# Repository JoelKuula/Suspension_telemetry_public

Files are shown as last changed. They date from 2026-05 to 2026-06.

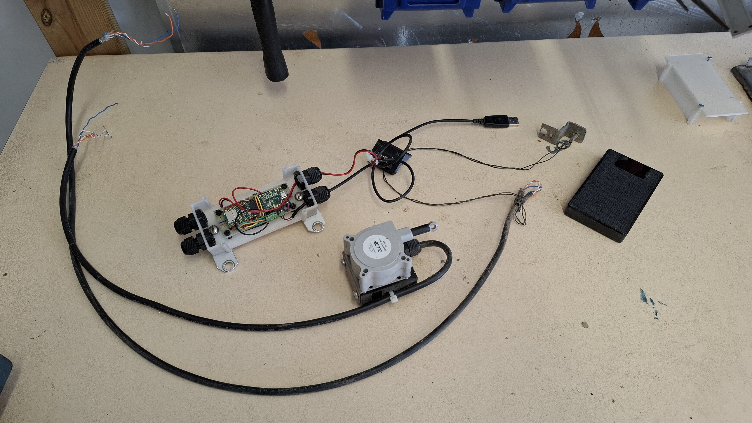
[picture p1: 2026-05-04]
pictures/bom-1.jpg

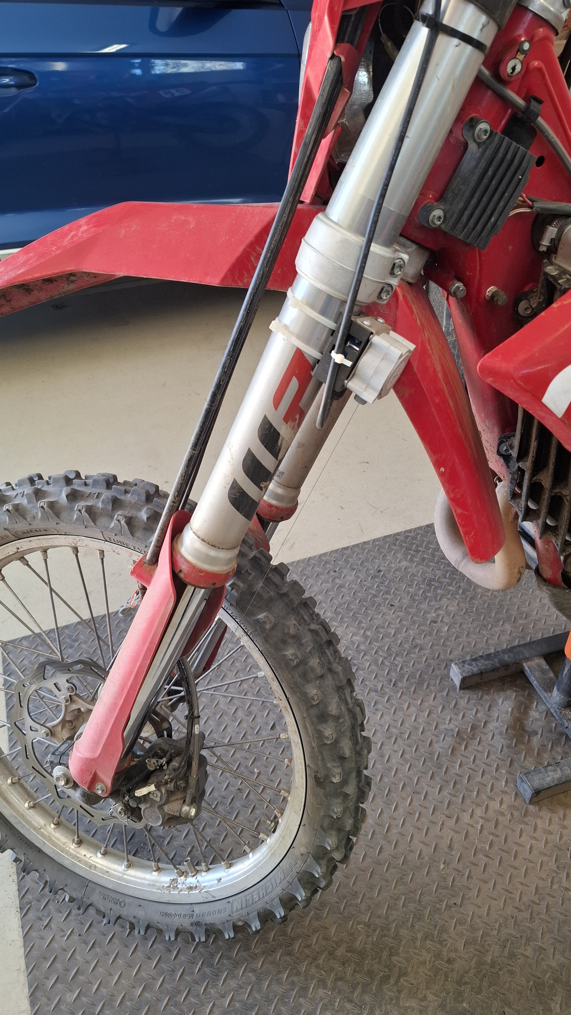
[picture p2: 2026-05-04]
pictures/installation-on-fork.jpg

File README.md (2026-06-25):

# Suspension Telemetry

DIY suspension telemetry logger and post-processing tools for enduro and motocross bikes.

The current project state is a prototype. The active logger slice uses a Teensy 4.1 to record front fork travel, rear shock stroke, front wheel pulse timing, status records, and RTC-backed session start timestamps.

This repo is intended to be useful to riders and builders who want to inspect, adapt, or improve the system. It is not a certified product or a complete suspension tuning solution.

## Prototype Status
- Active firmware scope: analog travel logging, front wheel pulse logging, status diagnostics, RTC-backed session metadata, and microSD binary session files.
- Active hardware baseline: Teensy 4.1, string potentiometer travel sensors (front only for now), front wheel reed switch, handlebar logging switch, microSD storage, RTC battery, and USB power-bank supply.
- Active analysis scope: binary inspection/export, desktop post-processing, occupancy/histogram views, speed checks, balance views (tbd), braking analysis, breakdown tables (tbd), and comparison workflows.

Read [`DISCLAIMER.md`](DISCLAIMER.md) before using this on a bike.

For the first public snapshot, see [`RELEASE_NOTES.md`](RELEASE_NOTES.md).

## Repository Layout
- [`HARDWARE.md`](HARDWARE.md): current hardware stack, mounting assumptions, and pinout.
- [`platformio.ini`](platformio.ini): PlatformIO project configuration for Teensy 4.1 firmware.
- [`src/main.cpp`](src/main.cpp): current integrated logger firmware.
- [`src/uploadcheck_blink.cpp`](src/uploadcheck_blink.cpp): minimal upload-check firmware using the external status LED on pin `14`.
- [`scripts/inspect_log.py`](scripts/inspect_log.py): parser and structural sanity checker for `.BIN` session files.
- [`scripts/export_log.py`](scripts/export_log.py): exporter from `.BIN` session files to CSV outputs.
- [`scripts/log_parser.py`](scripts/log_parser.py): shared binary parser used by the inspection and export tools.
- [`scripts/plot_occupancy_surface.py`](scripts/plot_occupancy_surface.py): CLI occupancy heatmap plotter.
- [`scripts/postprocess_gui.py`](scripts/postprocess_gui.py): desktop post-processing workbench launcher.
- [`scripts/postprocess_gui_app/`](scripts/postprocess_gui_app): shared backend services and PySide6 GUI implementation.
- [`scripts/postprocess_quicklook.py`](scripts/postprocess_quicklook.py): experimental Qt-free summary generator for `.BIN` files or existing exports.
- [`notebooks/trackside_quicklook.ipynb`](notebooks/trackside_quicklook.ipynb): experimental Colab wrapper for the quicklook path.
- [`data/`](data): sample raw `.BIN` sessions for parser, exporter, GUI, and analysis experiments.
- [`installation-pics/`](installation-pics): installation reference photos.
- [`3d-printed-parts-stl/`](3d-printed-parts-stl): STL files for prototype printed parts.
- [`tests/`](tests): backend and GUI regression tests for the analysis tooling.
- [`requirements.txt`](requirements.txt): Python dependencies for the post-processing tools.

Generated exports are intentionally not tracked. Running the exporter or GUI creates `exports/<session>/` locally.

## Quick Start
1. Read [`HARDWARE.md`](HARDWARE.md) before changing firmware, wiring, mounting, or sensor assumptions.
2. Install Python dependencies for post-processing:
   ```powershell
   python -m pip install -r requirements.txt
   ```
3. Inspect a sample log:
   ```powershell
   python scripts/inspect_log.py data/LOG00036.BIN
   ```
4. Export a sample log:
   ```powershell
   python scripts/export_log.py data/LOG00036.BIN --output-dir exports/LOG00036
   ```
5. Launch the desktop workbench on Windows:
   ```powershell
   .\postprocess_gui.cmd
   ```

The workbench can open a raw `.BIN` file and refresh `exports/<session>/`, or open an existing local export folder directly. GUI-derived caches and plots live under `exports/<session>/analysis/` and are generated locally.

## Firmware
The current integrated firmware target is the analog-plus-wheel ride logger in [`src/main.cpp`](src/main.cpp). It is designed around:
- deterministic analog sampling,
- wheel pulses as timestamped events,
- status records for boot/session/fault evidence,
- RTC-backed session start metadata,
- SD storage as a background path rather than an acquisition timing dependency.

Build with PlatformIO:
```powershell
platformio run -e teensy41
```

Use the upload-check firmware only when USB programming behavior needs to be isolated from the logger:
```powershell
platformio run -e teensy41_uploadcheck
```

## Desktop Workbench
Main views:
- `Session`: export summary, record counts, and status/fault rows.
- `Histograms`: front and rear travel plus velocity occupancy distributions.
- `Occupancy`: front and rear velocity-travel heatmaps.
- `Balance`: front/rear normalized travel comparison (tbd).
- `Braking`: front braking behavior.
- `Breakdown`: riding-state, event, finding, and data-quality tables (tbd).
- `Speed`: front wheel pulse-derived speed and pulse period.
- `Metrics`: per-channel stroke, velocity, and ADC checks.
- `Compare`: multi-session comparison workflow.

Per-session calibration is stored locally in `exports/<session>/analysis/session_config.json`.

## Experimental Quicklook
The quicklook path exists, but it is not the primary supported workflow yet. It can generate a small text/JSON summary and two figures without the PySide6 desktop GUI:
```powershell
python scripts/postprocess_quicklook.py --input data/LOG00036.BIN
```

Default outputs are written under `exports/<session>/analysis/quicklook/`.

## Sample Data
The repo keeps selected raw `.BIN` files under [`data/`](data), including the newer `LOG00041.BIN` through `LOG00053.BIN` sessions, so users can try the parser, exporter, quicklook script, GUI, and braking-analysis workflow without first building hardware.

Generated CSV exports, derived Parquet caches, plots, and per-session local calibration files are ignored because they can be regenerated from the raw `.BIN` files.

## Safety And Secrets
- Do not commit secrets, credentials, tokens, private keys, or private ride metadata.
- Treat bike-mounted hardware changes as safety-relevant.
- Verify wiring, power, waterproofing, and mechanical clearance before riding.
- Do not rely on the analysis output as professional suspension advice.

## License
This project is released under the [`MIT License`](LICENSE). MIT is permissive: others may use, copy, modify, merge, publish, distribute, sublicense, and sell copies, but the copyright and permission notice must be included with copies or substantial portions of the project.

## Contributing
Focused improvements are welcome. Please keep hardware assumptions explicit, preserve raw timing/data-model traceability, and update README/HARDWARE when architecture, hardware, wiring, or scope changes materially.

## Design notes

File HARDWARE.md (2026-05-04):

# HARDWARE

Current hardware baseline for the suspension telemetry logger.

## In Use Now
- MCU and logger: Teensy 4.1
- RTC backup: Teensy 4.1 RTC with CR2032 backup battery
- IMU hardware retained for later: SparkFun 6DoF IMU Breakout, `ISM330DHCX` (`SEN-19764`)
- Travel sensor currently installed: TE Connectivity `SP1-25` string potentiometer for fork testing
- Planned second travel sensor: likely TE Connectivity `SP1-12` for shock testing after fork validation
- Speed sensor: front wheel reed switch plus magnet
- Storage: Teensy 4.1 microSD
- User control: handlebar-mounted latching rocker switch for logging start and stop
- Power: USB power bank into the Teensy USB connector
- Packaging target: rigid under-seat enclosure near the bike center mass

## Current State
- The logger has already powered up and run successfully in bench-style living-room testing.
- The active firmware slice logs analog travel, front wheel speed, status events, and RTC-backed session start metadata.
- The IMU hardware is the `ISM330DHCX`, but active IMU logging is deferred until the enclosure and mounting arrangement are rigid enough for meaningful data.
- When IMU logging returns, it will use primary 4-wire SPI, not Qwiic or I2C.
- The intended long-term IMU mounting location remains under the seat on a rigidly mounted logger assembly.
- Logged bike-axis convention is `+X forward`, `+Y left`, `+Z up`.
- Rear suspension measurement remains raw shock stroke only; any wheel-travel conversion is an offline step.
- Wheel speed comes from the front wheel only.
- The string pot excitation baseline is the Teensy `3.3V` rail.
- Teensy 4.1 `LED_BUILTIN` shares pin `13`, so firmware must not use the built-in LED while pin `13` is the IMU SPI clock.
- The RTC remains in use because wall-clock session start times are useful for later BIN indexing and database work.
- Remaining hardware details to finalize later: analog filtering and protection, power-bank auto-shutdown mitigation, IMU remounting, and environmental sealing.

## IMU SPI Wiring
Reserved for the future IMU-return slice; not used by the current analog-plus-wheel firmware.

SparkFun labels the SPI pins from the sensor-board side:
- `SCL/SPC` -> Teensy pin `13` (`SCK`)
- `SDA/SDI` -> Teensy pin `11` (`PICO/MOSI`)
- `SDO/SA0` -> Teensy pin `12` (`POCI/MISO`)
- `CS` -> Teensy pin `10`
- `INT1` -> Teensy pin `2`
- `INT2` -> Teensy pin `3` if needed later

Do not confuse these with the auxiliary interface pins such as `SDX`, `SCX`, `SDO_AUX`, `POCI_AUX`, or `OCS_AUX`.

## Pinout

| Function | Device wire / signal | Teensy 4.1 pin | Notes |
| --- | --- | --- | --- |
| Fork travel sensor | `SP1-25 +in` | `3.3V` | Excitation supply |
| Fork travel sensor | `SP1-25 common` | `GND` | Sensor ground |
| Fork travel sensor | `SP1-25 +out / wiper` | `20 (A6)` | Analog input |
| Shock travel sensor, planned | `SP1-12 +in` | `3.3V` | Planned second analog channel |
| Shock travel sensor, planned | `SP1-12 common` | `GND` | Planned second analog ground |
| Shock travel sensor, planned | `SP1-12 +out / wiper` | `19 (A5)` | Planned second analog input |
| IMU power | `VCC` | `3.3V` | SparkFun board is `3.3V` logic and supply |
| IMU power | `GND` | `GND` | Common ground |
| IMU SPI | `SCL / SPC` | `13` | SPI clock |
| IMU SPI | `SDA / SDI` | `11` | Teensy `PICO/MOSI` |
| IMU SPI | `SDO / SA0` | `12` | Teensy `POCI/MISO` |
| IMU SPI | `CS` | `10` | Chip select |
| IMU interrupt | `INT1` | `2` | Reserved for future IMU-return slice |
| IMU interrupt, optional | `INT2` | `3` | Reserve if needed later |
| Wheel speed | Reed switch wire 1 | `18` | Configure as `INPUT_PULLUP` |
| Wheel speed | Reed switch wire 2 | `GND` | Switch closes to ground |
| Handlebar logging switch | Switch wire 1 | `17` | Configure as `INPUT_PULLUP`; flipped on pulls the pin low |
| Handlebar logging switch | Switch wire 2 | `GND` | Latching switch returns high when flipped off |
| USB power | Teensy USB connector | USB power bank | Main supply path |

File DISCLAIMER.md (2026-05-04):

# Disclaimer

This repository documents and implements a DIY prototype telemetry logger for motorcycle suspension development. It is not a certified safety device, commercial product, professional suspension tuning system, or substitute for mechanical inspection and judgment.

Use this project at your own risk. Verify all wiring, mounting, waterproofing, strain relief, power supply behavior, sensor clearances, and enclosure retention before riding. A loose sensor, cable, printed part, enclosure, or battery can interfere with motorcycle controls or moving parts.

The firmware, hardware notes, 3D models, photos, data files, scripts, analysis outputs, and documentation are provided without warranty. The author is not responsible for injury, damage, data loss, incorrect measurements, incorrect tuning decisions, regulatory issues, or any other consequence from using or adapting this project.

Analysis results are experimental. They may be wrong because of calibration errors, sensor noise, mounting flex, missed pulses, file corruption, software bugs, or incorrect assumptions about the motorcycle. Validate any conclusion independently before changing suspension setup or riding behavior.

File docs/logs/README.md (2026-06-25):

# Task Log Archives

Use this folder for archived task history when the active `TASK_LOG.md` becomes hard to scan.

## Naming Convention
Use one of these patterns:
- `TASK_LOG_YYYY_Q1.md`
- `TASK_LOG_YYYY_Q2.md`
- `TASK_LOG_YYYY_Q3.md`
- `TASK_LOG_YYYY_Q4.md`
- `TASK_LOG_<phase>.md`

Quarter-based naming is the default. Phase-based naming is fine when the project has clear stages and quarter splits would be less useful.

## Archive Trigger Rule
Archive older entries when the active `TASK_LOG.md` becomes hard to scan during normal work.

Signals that it is time to archive:
- important recent entries are getting buried,
- the file is slow to review at task start,
- the log contains multiple completed phases that no longer need to stay in the active file.

## Archive Rules
- Keep `TASK_LOG.md` as the active working log.
- Move only older completed entries into archive files.
- Preserve chronological order inside each archive file.
- Leave recent or currently relevant entries in the active log.
- Add a short note in `TASK_LOG.md` if a large archive move would otherwise confuse future readers.

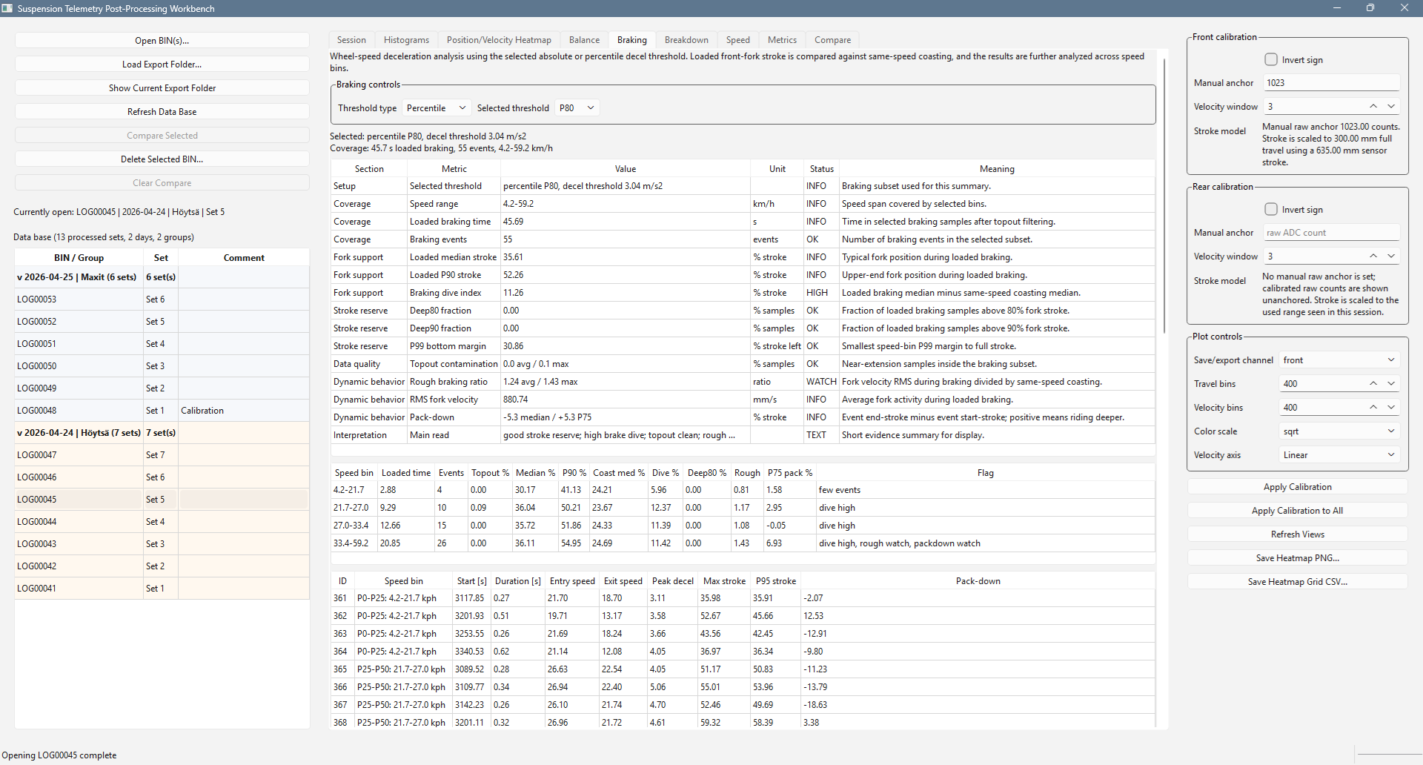
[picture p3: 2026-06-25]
pictures/workbench-example-braking.png

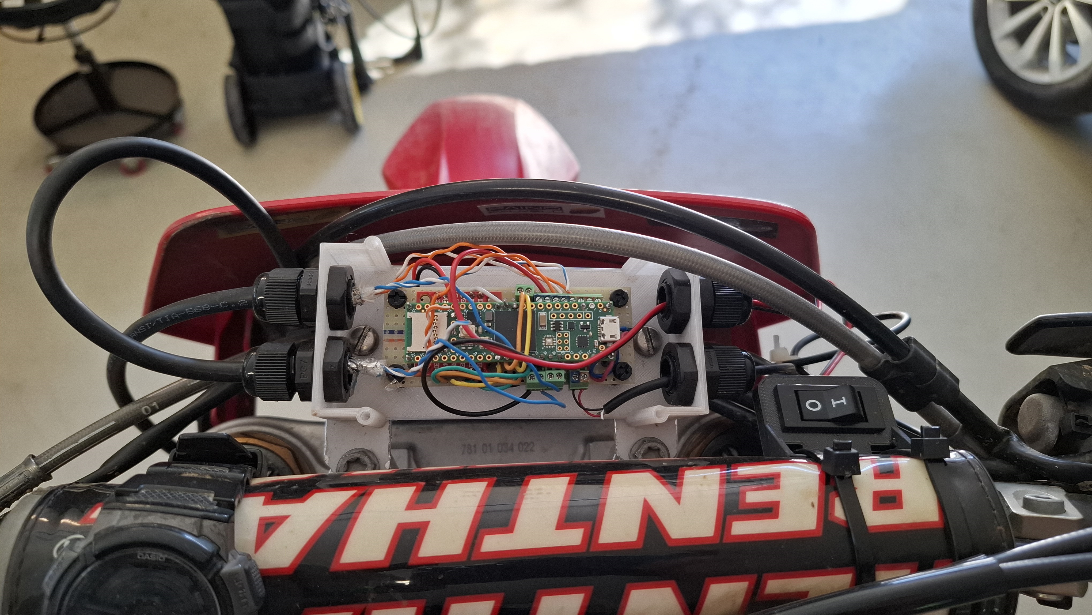
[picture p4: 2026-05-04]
pictures/pcb-mounting.jpg

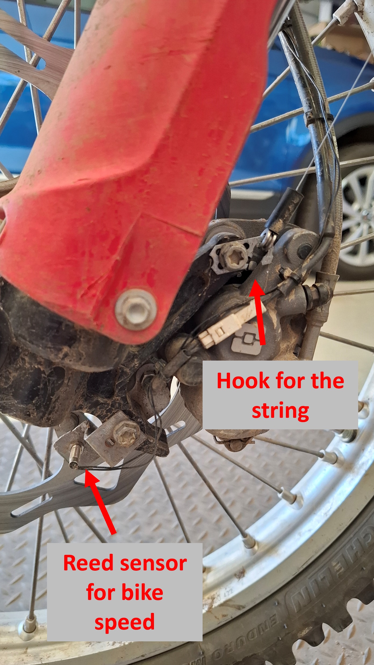
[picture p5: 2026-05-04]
pictures/string-pot-attachment-and-speed-sensor.png

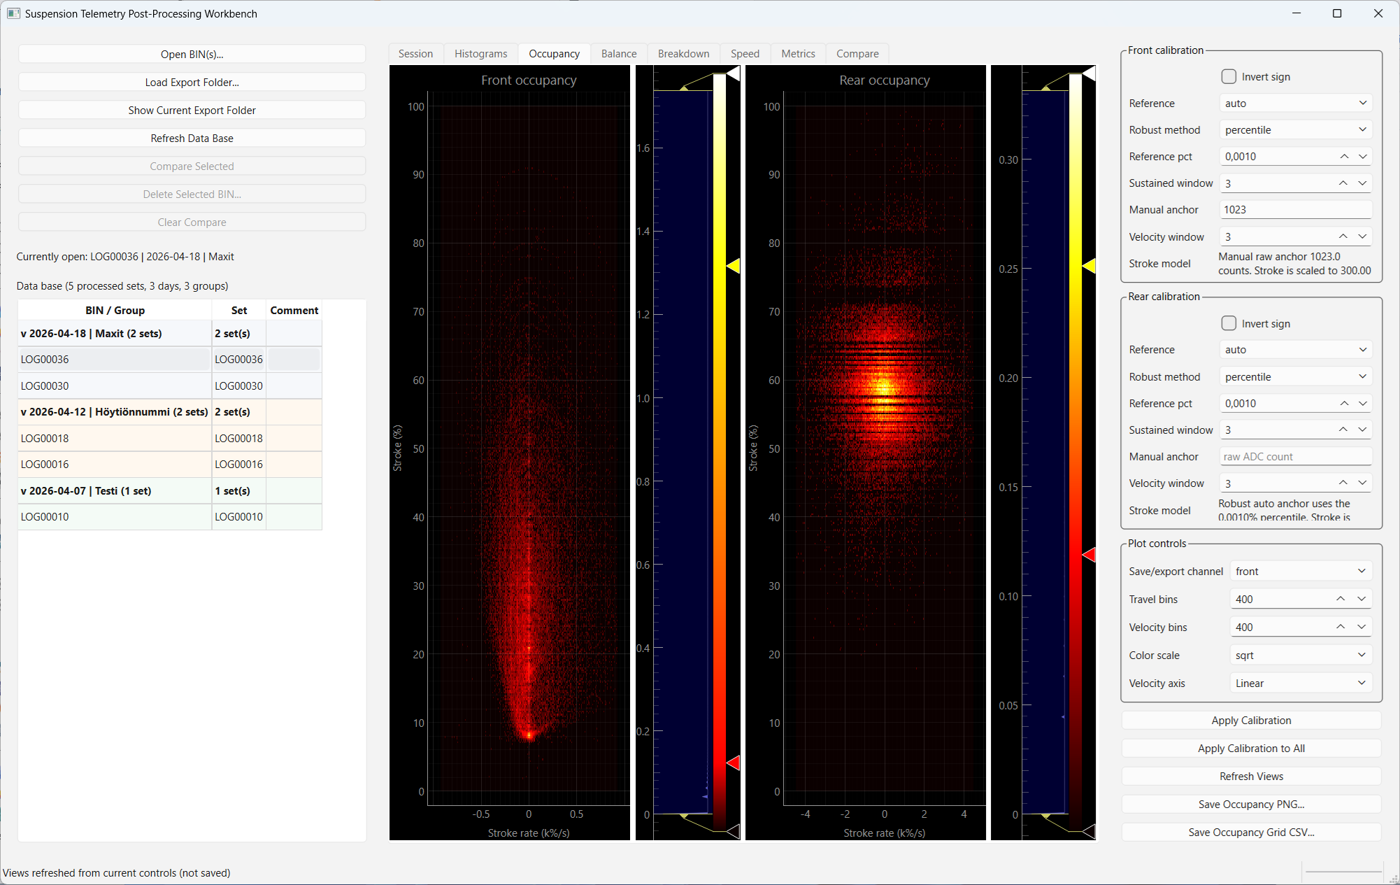
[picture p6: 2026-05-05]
pictures/workbench-example-2.png

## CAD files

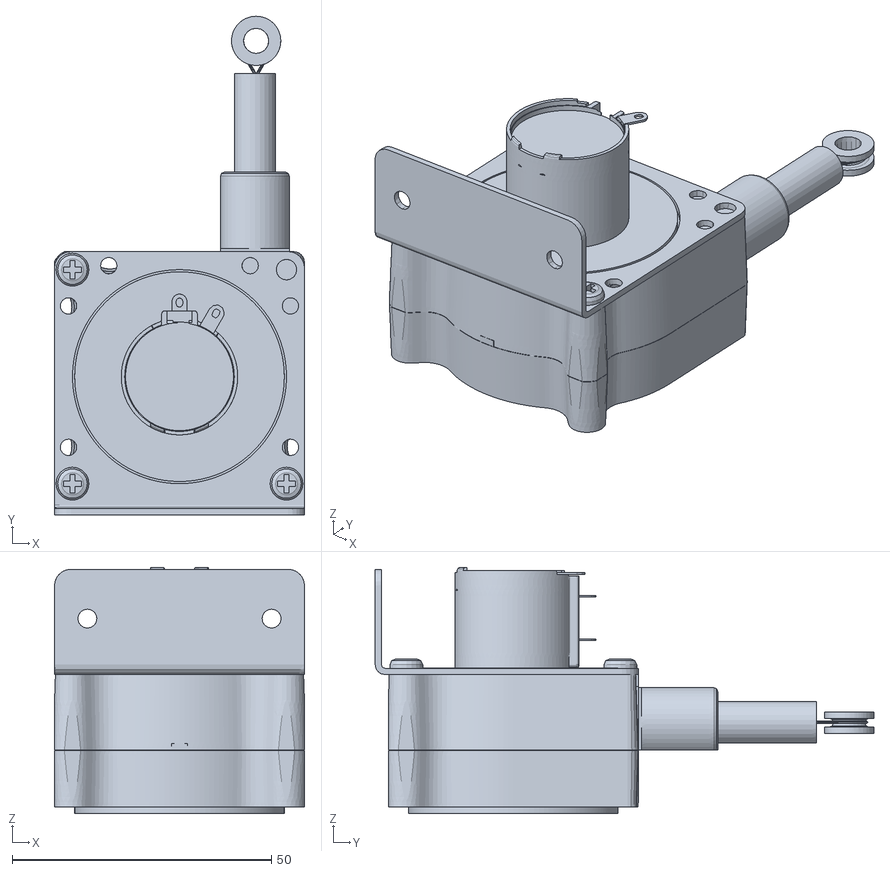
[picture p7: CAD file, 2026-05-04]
3d-printed-parts-stl/sp1-12.stl
48.3 x 96.3 x 47.6

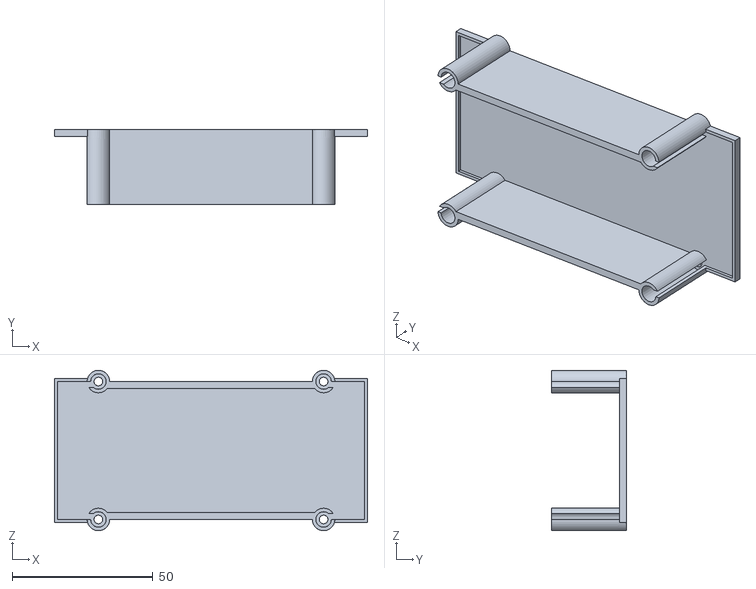
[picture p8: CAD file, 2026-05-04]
3d-printed-parts-stl/lid.stl
111.2 x 26.5 x 57.0

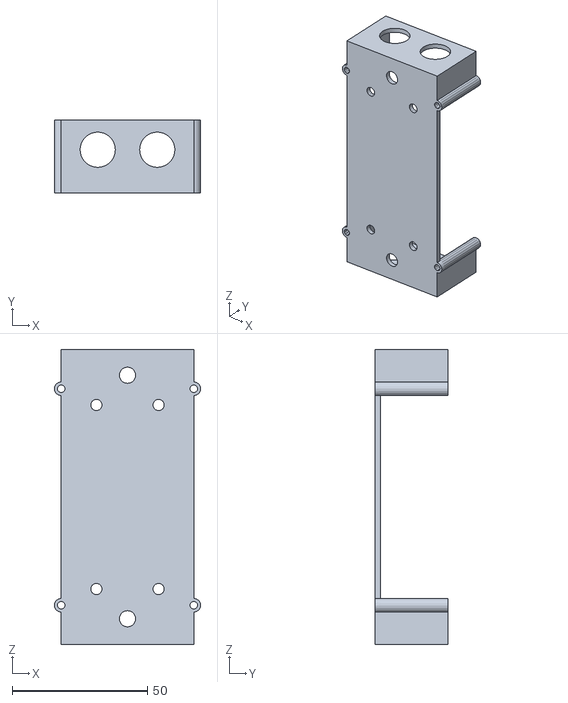
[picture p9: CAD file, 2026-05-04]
3d-printed-parts-stl/box.stl
54.0 x 27.0 x 109.0

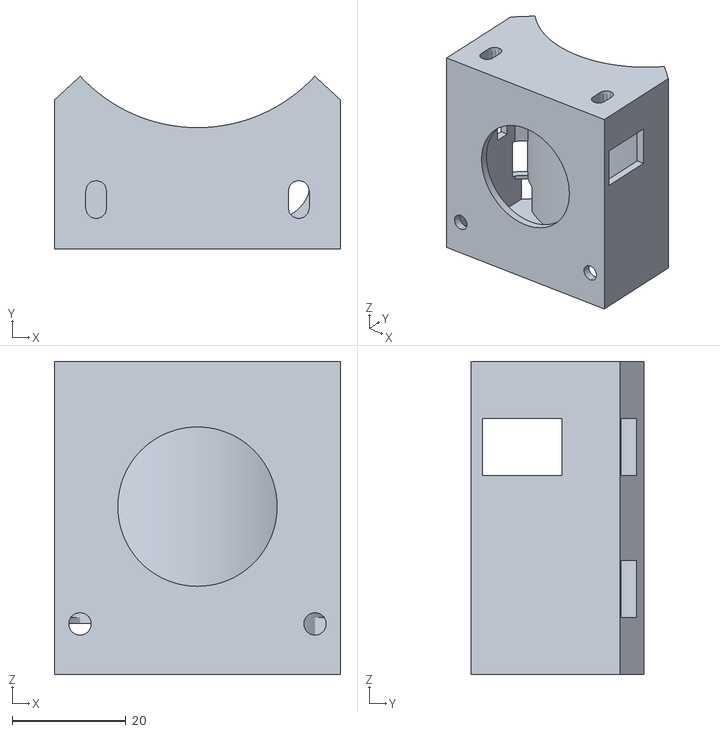
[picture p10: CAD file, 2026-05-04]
3d-printed-parts-stl/sp1_bracket.stl
50.3 x 30.3 x 55.0

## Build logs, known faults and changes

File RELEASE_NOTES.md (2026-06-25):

# v0.1-prototype

First public prototype snapshot of the DIY suspension telemetry project.

## Included
- Teensy 4.1 analog-plus-wheel logger firmware.
- Hardware wiring reference.
- Sample `.BIN` log files for parser, exporter, quicklook, and GUI experiments.
- Python parser/export tools.
- Desktop post-processing GUI.
- Experimental quicklook script and Colab notebook.
- Installation reference photos.
- Prototype STL files for printed parts.

## Post-processing GUI update
- Added the Python Braking view.
- Added newer raw `.BIN` sample sessions (`LOG00041.BIN` through `LOG00053.BIN`) so people can try the current GUI and analysis paths with real data.

## Known Limitations
- Prototype only; not a certified safety device or professional suspension tuning system.
- Active IMU logging is deferred until the logger can be mounted rigidly enough for useful inertial data.
- Analysis outputs are experimental and may be affected by calibration, sensor noise, mounting flex, missed pulses, or software bugs.
- Generated `exports/` are not tracked and should be regenerated from `.BIN` files.
- Rear channel represents shock stroke, not rear wheel travel.

## Safety
Read `DISCLAIMER.md` before using this project on a motorcycle.

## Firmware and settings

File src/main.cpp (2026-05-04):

#include <Arduino.h>
#include <IntervalTimer.h>
#include <SD.h>
#include <TimeLib.h>

#include <cstdio>
#include <cstring>

namespace {

constexpr uint8_t kButtonPin = 17;
constexpr uint8_t kLedPin = 14;
constexpr uint8_t kReedPin = 18;
constexpr uint8_t kFrontPotPin = A6;
constexpr uint8_t kRearPotPin = A5;
constexpr uint8_t kImuCsPin = 10;
constexpr uint8_t kImuInt1Pin = 2;

constexpr uint32_t kDebounceMs = 20;
constexpr uint32_t kArmBlinkMs = 120;

constexpr uint32_t kAnalogSampleRateHz = 500;
constexpr uint32_t kAnalogTimerPeriodUs = 1000000UL / kAnalogSampleRateHz;
constexpr uint8_t kAnalogResolutionBits = 12;
constexpr uint8_t kAnalogAveraging = 8;
// At 500 Hz each pending slot represents 2 ms of service latency. Eight slots
// were not enough to ride through occasional SD flush stalls seen in ride logs,
// so keep a larger timestamp cushion without changing the sample schedule.
constexpr uint16_t kAnalogMaxPendingTicks = 32;
constexpr uint8_t kAnalogTimestampCapacity = kAnalogMaxPendingTicks;

constexpr uint32_t kReedDebounceUs = 3000;
constexpr float kWheelCircumferenceM = 2.213f;

constexpr size_t kWriterBufferBytes = 65536;
constexpr size_t kWriterChunkBytes = 1024;
constexpr uint32_t kWriterFlushIntervalMs = 250;
constexpr uint32_t kFlushTimeoutMs = 5000;

constexpr uint32_t kMinValidRtcEpoch = 1704067200UL;
constexpr uint16_t kFormatVersion = 1;
constexpr uint32_t kFirmwareVersion = 0x00010000UL;

#ifdef LOGGER_VALIDATION_AUTORUN
constexpr uint32_t kValidationStartDelayMs = 12000;
constexpr uint32_t kValidationRunDurationMs = LOGGER_VALIDATION_DURATION_MS;
#endif

constexpr uint8_t kSensorMaskFrontAnalog = 0x01;
constexpr uint8_t kSensorMaskRearAnalog = 0x02;
constexpr uint8_t kSensorMaskWheel = 0x04;
constexpr uint8_t kSensorMaskRtc = 0x10;

enum class LoggerState : uint8_t {
  IDLE,
  LOGGING,
};

enum class StatCode : uint16_t {
  BOOT = 1,
  RTC_VALID = 2,
  RTC_INVALID = 3,
  SD_READY = 4,
  SD_ERROR = 5,
  IMU_READY = 6,
  IMU_ERROR = 7,
  SESSION_START = 8,
  SESSION_STOP = 9,
  CLEAN_CLOSE = 10,
  QUEUE_OVERFLOW = 11,
  ANALOG_OVERRUN = 12,
  REED_OVERFLOW = 13,
  IMU_FIFO_OVERFLOW = 14,
  WRITER_ERROR = 15,
  IMU_READ_ERROR = 16,
};

enum class SessionStopReason : int32_t {
  UNKNOWN = 0,
  SWITCH_OFF = 1,
  VALIDATION_AUTORUN = 2,
};

struct RingBuffer {
  uint8_t data[kWriterBufferBytes] = {};
  size_t head = 0;
  size_t tail = 0;
  size_t size = 0;

  void reset() {
    head = 0;
    tail = 0;
    size = 0;
  }

  size_t freeSpace() const { return kWriterBufferBytes - size; }

  bool push(const uint8_t* bytes, size_t length) {
    if (length > freeSpace()) {
      return false;
    }

    size_t first_chunk = length;
    const size_t head_to_end = kWriterBufferBytes - head;
    if (first_chunk > head_to_end) {
      first_chunk = head_to_end;
    }

    memcpy(&data[head], bytes, first_chunk);
    const size_t remaining = length - first_chunk;
    if (remaining > 0) {
      memcpy(data, bytes + first_chunk, remaining);
    }

    head = (head + length) % kWriterBufferBytes;
    size += length;
    return true;
  }

  size_t contiguousReadable() const {
    if (size == 0) {
      return 0;
    }
    if (head > tail) {
      return head - tail;
    }
    return kWriterBufferBytes - tail;
  }

  const uint8_t* readPtr() const { return &data[tail]; }

  void pop(size_t length) {
    if (length > size) {
      length = size;
    }
    tail = (tail + length) % kWriterBufferBytes;
    size -= length;
  }
};

struct ReedEvent {
  uint32_t timestamp_us;
  uint32_t interval_us;
  uint32_t pulse_count;
};

constexpr uint8_t kReedEventCapacity = 32;
volatile ReedEvent gReedEvents[kReedEventCapacity] = {};
volatile uint8_t gReedHead = 0;
volatile uint8_t gReedTail = 0;
volatile uint8_t gReedCount = 0;
volatile uint32_t gReedDropped = 0;
volatile uint32_t gReedPulseCount = 0;
volatile uint32_t gReedLastPulseUs = 0;

volatile bool gSessionActive = false;
volatile uint32_t gAnalogTickTimestampsUs[kAnalogTimestampCapacity] = {};
volatile uint8_t gAnalogTimestampHead = 0;
volatile uint8_t gAnalogTimestampTail = 0;
volatile uint16_t gAnalogTicksPending = 0;
volatile uint32_t gAnalogTickOverruns = 0;

IntervalTimer gAnalogTimer;
File gSessionFile;
RingBuffer gWriterBuffer;

LoggerState gLoggerState = LoggerState::IDLE;
bool gLoggerRunning = false;
bool gLastRawButtonPressed = false;
bool gStableButtonPressed = false;
bool gLastStableButtonPressed = false;
uint32_t gLastRawChangeMs = 0;

bool gSdReady = false;
bool gRtcValid = false;
bool gFaultLatched = false;
uint32_t gRtcEpochAtBoot = 0;

uint32_t gSessionIndex = 0;
char gSessionFilename[16] = {};
uint32_t gSessionStartEpoch = 0;
uint32_t gSessionStartMicros = 0;
uint32_t gRecordSequence = 0;
uint32_t gAnalogSampleIndex = 0;
uint32_t gLastWriterFlushMs = 0;

uint32_t gDroppedRecordCount = 0;
uint32_t gLastDroppedTag = 0;
uint32_t gReportedDroppedRecordCount = 0;

uint32_t gReportedAnalogTickOverruns = 0;
uint32_t gReportedReedDropped = 0;
uint32_t gWriterErrorCount = 0;
uint32_t gReportedWriterErrorCount = 0;

#ifdef LOGGER_VALIDATION_AUTORUN
bool gValidationAutoStartPending = false;
bool gValidationDumpPending = false;
uint32_t gValidationArmedAtMs = 0;
uint32_t gValidationStopAtMs = 0;
#endif

#pragma pack(push, 1)
struct SessionFileHeader {
  char magic[8];
  uint16_t format_version;
  uint16_t header_size;
  uint32_t firmware_version;
  uint32_t build_epoch;
  char build_id[24];
  uint32_t start_epoch;
  uint32_t start_micros;
  uint32_t session_index;
  uint8_t rtc_valid;
  uint8_t enabled_mask;
  uint8_t analog_resolution_bits;
  uint8_t analog_averaging;
  uint16_t analog_rate_hz;
  uint16_t imu_rate_hz;
  uint16_t imu_watermark_frames;
  uint16_t record_header_size;
  uint8_t button_pin;
  uint8_t led_pin;
  uint8_t reed_pin;
  uint8_t imu_int1_pin;
  uint8_t front_pot_pin;
  uint8_t rear_pot_pin;
  uint8_t imu_cs_pin;
  uint8_t reserved0;
  uint32_t reserved[6];
};

struct RecordHeader {
  char tag[4];
  uint16_t payload_length;
  uint16_t flags;
  uint32_t sequence;
  uint32_t host_timestamp_us;
};

struct ConfigPayload {
  uint16_t analog_rate_hz;
  uint8_t analog_resolution_bits;
  uint8_t analog_averaging;
  uint32_t button_debounce_ms;
  uint32_t button_hold_start_ms;
  uint32_t button_hold_stop_ms;
  uint32_t reed_debounce_us;
  float wheel_circumference_m;
  uint16_t imu_accel_range_g;
  uint16_t imu_gyro_range_dps;
  uint16_t imu_odr_hz;
  uint16_t imu_watermark_frames;
  uint8_t imu_fifo_mode;
  uint8_t imu_timestamp_decimation;
  uint16_t reserved;
};

struct StatPayload {
  uint16_t code;
  uint16_t flags;
  int32_t value0;
  int32_t value1;
};

struct AnalogPayload {
  uint32_t sample_index;
  uint16_t front_raw;
  uint16_t rear_raw;
};

struct WheelPayload {
  uint32_t pulse_count;
  uint32_t interval_us;
};
#pragma pack(pop)

static_assert(sizeof(SessionFileHeader) == 100, "SessionFileHeader size changed");
static_assert(sizeof(RecordHeader) == 16, "RecordHeader size changed");

bool startLogging();
void stopLogging(SessionStopReason reason = SessionStopReason::UNKNOWN);

uint32_t packFourCc(const char* tag) {
  return uint32_t(uint8_t(tag[0])) | (uint32_t(uint8_t(tag[1])) << 8) |
         (uint32_t(uint8_t(tag[2])) << 16) | (uint32_t(uint8_t(tag[3])) << 24);
}

time_t getTeensy3Time() { return Teensy3Clock.get(); }

uint8_t monthFromAbbrev(const char* mon) {
  if (strcmp(mon, "Jan") == 0) return 1;
  if (strcmp(mon, "Feb") == 0) return 2;
  if (strcmp(mon, "Mar") == 0) return 3;
  if (strcmp(mon, "Apr") == 0) return 4;
  if (strcmp(mon, "May") == 0) return 5;
  if (strcmp(mon, "Jun") == 0) return 6;
  if (strcmp(mon, "Jul") == 0) return 7;
  if (strcmp(mon, "Aug") == 0) return 8;
  if (strcmp(mon, "Sep") == 0) return 9;
  if (strcmp(mon, "Oct") == 0) return 10;
  if (strcmp(mon, "Nov") == 0) return 11;
  if (strcmp(mon, "Dec") == 0) return 12;
  return 1;
}

uint32_t compileTimeToEpoch() {
  char mon[4] = {};
  int day = 1;
  int year = 2026;
  int hour_value = 0;
  int minute_value = 0;
  int second_value = 0;

  sscanf(__DATE__, "%3s %d %d", mon, &day, &year);
  sscanf(__TIME__, "%d:%d:%d", &hour_value, &minute_value, &second_value);

  tmElements_t tm = {};
  tm.Year = CalendarYrToTm(year);
  tm.Month = monthFromAbbrev(mon);
  tm.Day = day;
  tm.Hour = hour_value;
  tm.Minute = minute_value;
  tm.Second = second_value;
  return makeTime(tm);
}

void formatDateTime(time_t value, char* buffer, size_t buffer_size) {
  if (buffer_size == 0) {
    return;
  }

  if (value == 0) {
    snprintf(buffer, buffer_size, "0000-00-00 00:00:00");
    return;
  }

  tmElements_t tm = {};
  breakTime(value, tm);
  snprintf(buffer, buffer_size, "%04d-%02d-%02d %02d:%02d:%02d", tmYearToCalendar(tm.Year), tm.Month, tm.Day,
           tm.Hour, tm.Minute, tm.Second);
}

void setLed(bool on) { digitalWrite(kLedPin, on ? HIGH : LOW); }

bool loggingPattern(uint32_t now_ms) {
  const uint32_t t = now_ms % 1200UL;
  return (t < 80UL) || (t >= 200UL && t < 280UL);
}

bool fastBlinkPattern(uint32_t now_ms) { return ((now_ms / kArmBlinkMs) % 2UL) == 0; }

void analogTimerIsr() {
  if (!gSessionActive) {
    return;
  }

  if (gAnalogTicksPending < kAnalogMaxPendingTicks) {
    // Capture the timer tick time in the ISR so ANLG records reflect sampling schedule,
    // not the later main-loop service latency.
    gAnalogTickTimestampsUs[gAnalogTimestampHead] = micros();
    gAnalogTimestampHead = uint8_t((gAnalogTimestampHead + 1U) % kAnalogTimestampCapacity);
    ++gAnalogTicksPending;
  } else {
    ++gAnalogTickOverruns;
  }
}

void resetReedState() {
  noInterrupts();
  gReedHead = 0;
  gReedTail = 0;
  gReedCount = 0;
  gReedDropped = 0;
  gReedPulseCount = 0;
  gReedLastPulseUs = 0;
  interrupts();
}

void reedIsr() {
  if (!gSessionActive) {
    return;
  }

  const uint32_t now_us = micros();
  const uint32_t last_pulse_us = gReedLastPulseUs;
  if (last_pulse_us != 0 && (uint32_t)(now_us - last_pulse_us) < kReedDebounceUs) {
    return;
  }

  const uint32_t next_pulse_count = gReedPulseCount + 1UL;
  const uint32_t interval_us = (last_pulse_us == 0) ? 0UL : (now_us - last_pulse_us);

  gReedPulseCount = next_pulse_count;
  gReedLastPulseUs = now_us;

  if (gReedCount >= kReedEventCapacity) {
    ++gReedDropped;
    return;
  }

  gReedEvents[gReedHead].timestamp_us = now_us;
  gReedEvents[gReedHead].interval_us = interval_us;
  gReedEvents[gReedHead].pulse_count = next_pulse_count;
  gReedHead = uint8_t((gReedHead + 1U) % kReedEventCapacity);
  ++gReedCount;
}

void waitForSerial() {
  Serial.begin(115200);
  const uint32_t start_ms = millis();
  while (!Serial && (millis() - start_ms) < 3000UL) {
    delay(10);
  }
}

bool isRtcUsable(time_t epoch_value) { return epoch_value >= kMinValidRtcEpoch; }

void initRtc() {
  setSyncProvider(getTeensy3Time);
  const time_t rtc_now = now();
  gRtcValid = (timeStatus() == timeSet) && isRtcUsable(rtc_now);
  gRtcEpochAtBoot = gRtcValid ? uint32_t(rtc_now) : 0UL;
}

bool initSd() {
  if (!SD.begin(BUILTIN_SDCARD)) {
    return false;
  }
  return true;
}

uint8_t enabledSensorMask() {
  uint8_t mask = kSensorMaskFrontAnalog | kSensorMaskRearAnalog | kSensorMaskWheel;
  if (gRtcValid) {
    mask |= kSensorMaskRtc;
  }
  return mask;
}

void fillBuildId(char* buffer, size_t buffer_size) {
  snprintf(buffer, buffer_size, "%s %s", __DATE__, __TIME__);
}

bool findNextSessionFilename(char* buffer, size_t buffer_size, uint32_t* session_index) {
  for (uint32_t candidate = 1; candidate <= 99999UL; ++candidate) {
    snprintf(buffer, buffer_size, "/LOG%05lu.BIN", static_cast<unsigned long>(candidate));
    if (!SD.exists(buffer)) {
      *session_index = candidate;
      return true;
    }
  }
  return false;
}

bool writeSessionHeader(uint32_t session_index, const char* filename, uint32_t start_epoch, uint32_t start_micros) {
  SessionFileHeader header = {};
  memcpy(header.magic, "STLOG1\0", 8);
  header.format_version = kFormatVersion;
  header.header_size = sizeof(header);
  header.firmware_version = kFirmwareVersion;
  header.build_epoch = compileTimeToEpoch();
  fillBuildId(header.build_id, sizeof(header.build_id));
  header.start_epoch = start_epoch;
  header.start_micros = start_micros;
  header.session_index = session_index;
  header.rtc_valid = gRtcValid ? 1U : 0U;
  header.enabled_mask = enabledSensorMask();
  header.analog_resolution_bits = kAnalogResolutionBits;
  header.analog_averaging = kAnalogAveraging;
  header.analog_rate_hz = kAnalogSampleRateHz;
  header.imu_rate_hz = 0;
  header.imu_watermark_frames = 0;
  header.record_header_size = sizeof(RecordHeader);
  header.button_pin = kButtonPin;
  header.led_pin = kLedPin;
  header.reed_pin = kReedPin;
  header.imu_int1_pin = kImuInt1Pin;
  header.front_pot_pin = kFrontPotPin;
  header.rear_pot_pin = kRearPotPin;
  header.imu_cs_pin = kImuCsPin;
  header.reserved[0] = packFourCc("CFG ");
  header.reserved[1] = packFourCc("STAT");
  header.reserved[2] = packFourCc("ANLG");
  header.reserved[3] = packFourCc("WSPD");
  header.reserved[4] = packFourCc("IMU ");
  header.reserved[5] = filename[1] ? filename[1] : 0;

  const size_t written = gSessionFile.write(reinterpret_cast<const uint8_t*>(&header), sizeof(header));
  return written == sizeof(header);
}

bool queueRecordRaw(const char* tag, uint16_t flags, uint32_t host_timestamp_us, const void* payload, uint16_t payload_length,
                    bool count_drops) {
  RecordHeader header = {};
  memcpy(header.tag, tag, 4);
  header.payload_length = payload_length;
  header.flags = flags;
  header.sequence = gRecordSequence++;
  header.host_timestamp_us = host_timestamp_us;

  const size_t total_size = sizeof(header) + payload_length;
  if (gWriterBuffer.freeSpace() < total_size) {
    if (count_drops) {
      ++gDroppedRecordCount;
      gLastDroppedTag = packFourCc(tag);
    }
    return false;
  }

  gWriterBuffer.push(reinterpret_cast<const uint8_t*>(&header), sizeof(header));
  if (payload_length > 0) {
    gWriterBuffer.push(reinterpret_cast<const uint8_t*>(payload), payload_length);
  }
  return true;
}

template <typename T>
bool queueRecord(const char* tag, uint16_t flags, uint32_t host_timestamp_us, const T& payload, bool count_drops = true) {
  return queueRecordRaw(tag, flags, host_timestamp_us, &payload, sizeof(T), count_drops);
}

bool queueStat(StatCode code, int32_t value0, int32_t value1, uint16_t flags = 0, bool count_drops = false,
               uint32_t host_timestamp_us = micros()) {
  StatPayload payload = {};
  payload.code = static_cast<uint16_t>(code);
  payload.flags = flags;
  payload.value0 = value0;
  payload.value1 = value1;
  return queueRecord("STAT", 0, host_timestamp_us, payload, count_drops);
}

bool queueConfigRecord() {
  ConfigPayload payload = {};
  payload.analog_rate_hz = kAnalogSampleRateHz;
  payload.analog_resolution_bits = kAnalogResolutionBits;
  payload.analog_averaging = kAnalogAveraging;
  payload.button_debounce_ms = kDebounceMs;
  payload.button_hold_start_ms = 0;
  payload.button_hold_stop_ms = 0;
  payload.reed_debounce_us = kReedDebounceUs;
  payload.wheel_circumference_m = kWheelCircumferenceM;
  payload.imu_accel_range_g = 0;
  payload.imu_gyro_range_dps = 0;
  payload.imu_odr_hz = 0;
  payload.imu_watermark_frames = 0;
  payload.imu_fifo_mode = 0;
  payload.imu_timestamp_decimation = 0;
  return queueRecord("CFG ", 0, gSessionStartMicros, payload);
}

bool flushWriterChunk() {
  if (!gSessionFile || gWriterBuffer.size == 0) {
    return true;
  }

  size_t length = gWriterBuffer.contiguousReadable();
  if (length > kWriterChunkBytes) {
    length = kWriterChunkBytes;
  }
  const size_t written = gSessionFile.write(gWriterBuffer.readPtr(), length);
  if (written == 0) {
    return false;
  }
  gWriterBuffer.pop(written);
  return true;
}

void noteWriterError() {
  ++gWriterErrorCount;
  gFaultLatched = true;
  Serial.println("Writer error");
}

bool flushWriterAll(uint32_t timeout_ms) {
  const uint32_t start_ms = millis();
  while (gWriterBuffer.size > 0) {
    if (!flushWriterChunk()) {
      noteWriterError();
      return false;
    }
    if ((millis() - start_ms) > timeout_ms) {
      noteWriterError();
      return false;
    }
  }
  gSessionFile.flush();
  gLastWriterFlushMs = millis();
  return true;
}

bool serviceWriter(bool force_flush) {
  if (!gSessionFile) {
    return false;
  }

  if (gWriterBuffer.size == 0) {
    if (force_flush) {
      gSessionFile.flush();
      gLastWriterFlushMs = millis();
    }
    return true;
  }

  if (!flushWriterChunk()) {
    noteWriterError();
    return false;
  }

  const uint32_t now_ms = millis();
  if (force_flush || (now_ms - gLastWriterFlushMs) >= kWriterFlushIntervalMs) {
    gSessionFile.flush();
    gLastWriterFlushMs = now_ms;
  }
  return true;
}

void emitStartupStats() {
  const int32_t ready_mask = (gSdReady ? 0x01 : 0x00) | (gRtcValid ? 0x04 : 0x00);
  queueStat(StatCode::BOOT, ready_mask, int32_t(gSessionIndex));
  if (gRtcValid) {
    queueStat(StatCode::RTC_VALID, int32_t(gSessionStartEpoch), 0);
  } else {
    queueStat(StatCode::RTC_INVALID, 0, 0);
  }
  queueStat(gSdReady ? StatCode::SD_READY : StatCode::SD_ERROR, gSdReady ? 1 : 0, 0);
  queueStat(StatCode::SESSION_START, int32_t(gSessionIndex), 0, 0, false, gSessionStartMicros);
}

void emitDeferredStats() {
  if (!gSessionFile) {
    return;
  }

  if (gDroppedRecordCount > gReportedDroppedRecordCount) {
    const uint32_t delta = gDroppedRecordCount - gReportedDroppedRecordCount;
    if (queueStat(StatCode::QUEUE_OVERFLOW, int32_t(delta), int32_t(gLastDroppedTag), 0, false)) {
      gReportedDroppedRecordCount = gDroppedRecordCount;
    }
  }

  if (gAnalogTickOverruns > gReportedAnalogTickOverruns) {
    const uint32_t delta = gAnalogTickOverruns - gReportedAnalogTickOverruns;
    if (queueStat(StatCode::ANALOG_OVERRUN, int32_t(delta), 0, 0, false)) {
      gReportedAnalogTickOverruns = gAnalogTickOverruns;
    }
  }

  if (gReedDropped > gReportedReedDropped) {
    const uint32_t delta = gReedDropped - gReportedReedDropped;
    if (queueStat(StatCode::REED_OVERFLOW, int32_t(delta), 0, 0, false)) {
      gReportedReedDropped = gReedDropped;
    }
  }

  if (gWriterErrorCount > gReportedWriterErrorCount) {
    const uint32_t delta = gWriterErrorCount - gReportedWriterErrorCount;
    if (queueStat(StatCode::WRITER_ERROR, int32_t(delta), 0, 0, false)) {
      gReportedWriterErrorCount = gWriterErrorCount;
    }
  }
}

bool popReedEvent(ReedEvent* event) {
  noInterrupts();
  if (gReedCount == 0) {
    interrupts();
    return false;
  }

  event->timestamp_us = gReedEvents[gReedTail].timestamp_us;
  event->interval_us = gReedEvents[gReedTail].interval_us;
  event->pulse_count = gReedEvents[gReedTail].pulse_count;
  gReedTail = uint8_t((gReedTail + 1U) % kReedEventCapacity);
  --gReedCount;
  interrupts();
  return true;
}

void serviceWheelEvents() {
  ReedEvent event = {};
  while (popReedEvent(&event)) {
    WheelPayload payload = {};
    payload.pulse_count = event.pulse_count;
    payload.interval_us = event.interval_us;
    queueRecord("WSPD", 0, event.timestamp_us, payload);
  }
}

uint16_t readPotSample(uint8_t pin) {
  // analogReadAveraging() already applies hardware-side averaging. Doing an
  // extra software loop here multiplies acquisition time and wastes margin in
  // the timer-driven analog service path.
  return uint16_t(analogRead(pin));
}

void serviceAnalogAcquisition() {
  while (true) {
    uint32_t sample_timestamp_us = 0;
    noInterrupts();
    if (gAnalogTicksPending == 0) {
      interrupts();
      break;
    }
    sample_timestamp_us = gAnalogTickTimestampsUs[gAnalogTimestampTail];
    gAnalogTimestampTail = uint8_t((gAnalogTimestampTail + 1U) % kAnalogTimestampCapacity);
    --gAnalogTicksPending;
    interrupts();

    AnalogPayload payload = {};
    payload.sample_index = gAnalogSampleIndex++;
    payload.front_raw = readPotSample(kFrontPotPin);
    payload.rear_raw = readPotSample(kRearPotPin);
    queueRecord("ANLG", 0, sample_timestamp_us, payload);
  }
}

#ifdef LOGGER_VALIDATION_AUTORUN
void dumpSessionFileHex() {
  if (gSessionFilename[0] == '\0') {
    Serial.println("VALIDATION_DUMP_ERROR missing filename");
    return;
  }

  File dump_file = SD.open(gSessionFilename, FILE_READ);
  if (!dump_file) {
    Serial.print("VALIDATION_DUMP_ERROR open ");
    Serial.println(gSessionFilename);
    return;
  }

  Serial.print("VALIDATION_DUMP_BEGIN ");
  Serial.print(gSessionFilename);
  Serial.print(" ");
  Serial.println(dump_file.size());

  constexpr char kHexDigits[] = "0123456789ABCDEF";
  uint8_t buffer[32] = {};
  char line[sizeof(buffer) * 2 + 1] = {};
  while (true) {
    const int bytes_read = dump_file.read(buffer, sizeof(buffer));
    if (bytes_read <= 0) {
      break;
    }

    for (int i = 0; i < bytes_read; ++i) {
      line[i * 2] = kHexDigits[(buffer[i] >> 4) & 0x0F];
      line[i * 2 + 1] = kHexDigits[buffer[i] & 0x0F];
    }
    line[bytes_read * 2] = '\0';
    Serial.println(line);
    Serial.send_now();
    delay(1);
  }

  dump_file.close();
  Serial.println("VALIDATION_DUMP_END");
  Serial.flush();
}
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
void loop() {
  const uint32_t now_ms = millis();

  updateDebouncedButton(now_ms);
  updateStateMachine(now_ms);
  updateLed(now_ms);

#ifdef LOGGER_VALIDATION_AUTORUN
  serviceValidationAutorun(now_ms);
#endif

  if (gLoggerRunning) {
    serviceAnalogAcquisition();
    serviceWheelEvents();
    emitDeferredStats();
    serviceWriter(false);
  }
}
